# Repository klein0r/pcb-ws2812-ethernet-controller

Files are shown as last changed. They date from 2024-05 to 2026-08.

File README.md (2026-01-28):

# WS2812 / SK6812 Ethernet Controller Custom PCB

Control your addressable LED with custom software like [WLED](https://github.com/Aircoookie/WLED)

[Gerber-Files](https://github.com/klein0r/pcb-ws2812-ethernet-controller/releases)

## Important notes

The [WT32-ETH01](https://en.wireless-tag.com/product-item-2.html) has been released in different revisions. This adapter has been tested with revision 1.2 (length of the WT32-ETH01 PCB is ~5.5 cm).

**Some revisions may not fit!** I've received a photo of revision 1.4 with a PCB length of ~6.0 cm. Use PCB version 2.0 (or later) of this project to ensure the adapter will fit.

## Preview

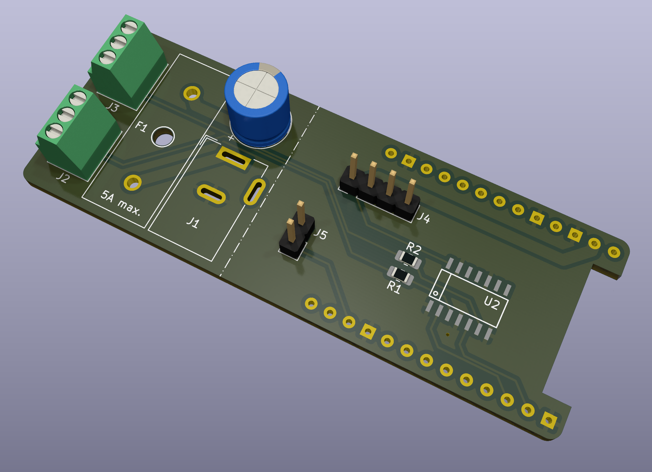
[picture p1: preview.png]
PCB Preview


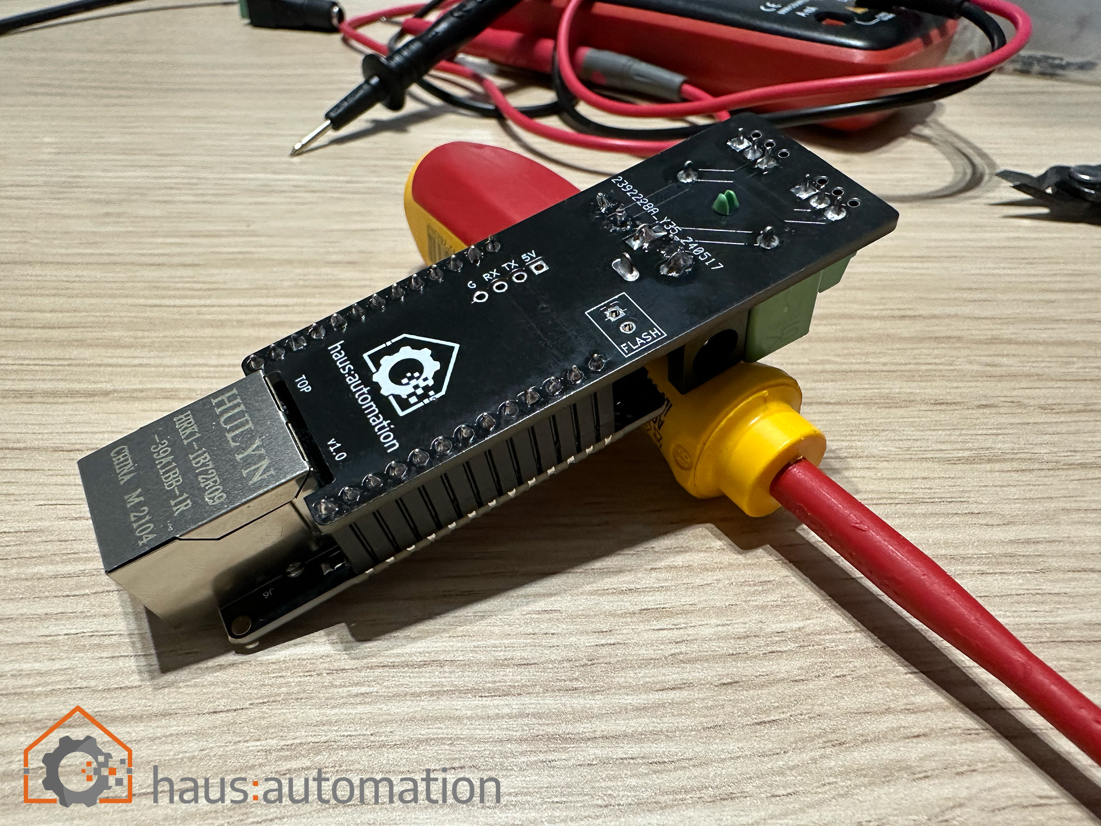
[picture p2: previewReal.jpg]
PCB Photo


## Components

- U1: WT32-ETH01 ESP32
- U2: SN74AHCT125DR
- C1: Capacitor Radial 3.8mm 1000μF 6.3V
- F1: Stelvio Kontek STV PTF/75 + Fuse 5x20mm, 5A (max. 6A)
- J1: Barrel Jack Connector - Wuerth 6941xx301002
- J2: PHC 1725669 - MPT 0,5 / 3-2,54
- J3: PHC 1725669 - MPT 0,5 / 3-2,54
- J4: 1x4 2.54mm Male Pin Headers (for flashing - soldering not required)
- J5: 1x2 2.54mm Male Pin Headers (for flashing - soldering not required / jumper)
- R1: Resistor 0805 330
- R2: Resistor 0805 330

[Component list (Affiliate-Link)](https://haus-auto.com/p/rei/ListeWS2812Eth)

## GPIO

- GPIO2 = Data line 1 of addressable strip
- GPIO4 = Data line 2 of addressable strip

## License

The MIT License (MIT)

Copyright (c) 2026 Matthias Kleine <info@haus-automatisierung.com>

Permission is hereby granted, free of charge, to any person obtaining a copy
of this software and associated documentation files (the "Software"), to deal
in the Software without restriction, including without limitation the rights
to use, copy, modify, merge, publish, distribute, sublicense, and/or sell
copies of the Software, and to permit persons to whom the Software is
furnished to do so, subject to the following conditions:

The above copyright notice and this permission notice shall be included in
all copies or substantial portions of the Software.

THE SOFTWARE IS PROVIDED "AS IS", WITHOUT WARRANTY OF ANY KIND, EXPRESS OR
IMPLIED, INCLUDING BUT NOT LIMITED TO THE WARRANTIES OF MERCHANTABILITY,
FITNESS FOR A PARTICULAR PURPOSE AND NONINFRINGEMENT. IN NO EVENT SHALL THE
AUTHORS OR COPYRIGHT HOLDERS BE LIABLE FOR ANY CLAIM, DAMAGES OR OTHER
LIABILITY, WHETHER IN AN ACTION OF CONTRACT, TORT OR OTHERWISE, ARISING FROM,
OUT OF OR IN CONNECTION WITH THE SOFTWARE OR THE USE OR OTHER DEALINGS IN
THE SOFTWARE.

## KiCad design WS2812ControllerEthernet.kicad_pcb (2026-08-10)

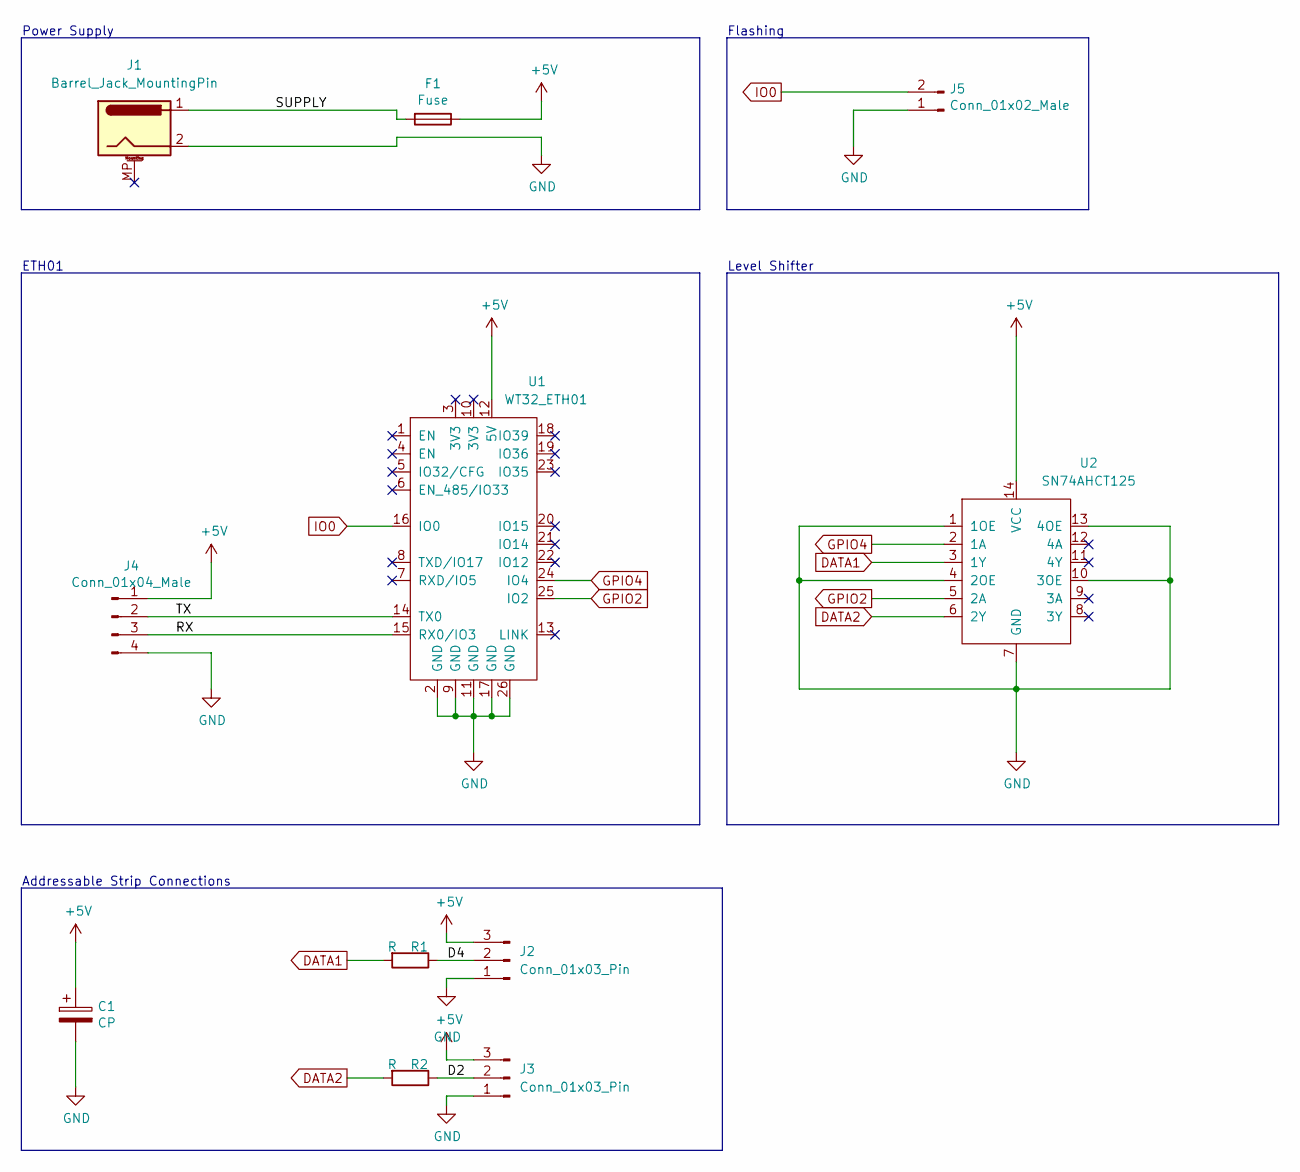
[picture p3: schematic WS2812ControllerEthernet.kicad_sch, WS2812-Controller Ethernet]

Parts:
C1: CP; CP_Radial_D8.0mm_P3.80mm
F1: Fuse; Fuse-PTF75_Stelvio
J1: Barrel_Jack_MountingPin; BarrelJack_Wuerth_6941xx301002
J2, J3: Conn_01x03_Pin; TerminalBlock_Phoenix_MPT-0,5-3-2.54_1x03_P2.54mm_Horizontal
J4: Conn_01x04_Male; PinHeader_1x04_P2.54mm_Vertical
J5: Conn_01x02_Male; PinHeader_1x02_P2.54mm_Vertical
R1, R2: R; R_0805_2012Metric_Pad1.20x1.40mm_HandSolder
U1: WT32_ETH01; WT32_ETH01_long
U2: SN74AHCT125; SN74AHCT125D

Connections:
+5V: C1.1, F1.1, J2.3, J3.3, J4.1, U1.12 (5V), U2.14 (VCC)
/D2: J3.2, R2.1
/D4: J2.2, R1.1
/RX: J4.3, U1.15 (RX0/IO3)
/SUPPLY: F1.2, J1.1
/TX: J4.2, U1.14 (TX0)
DATA1: R1.2, U2.3 (1Y)
DATA2: R2.2, U2.6 (2Y)
GND: C1.2, J1.2, J2.1, J3.1, J4.4, J5.1, U1.2 (GND), U1.9 (GND), U1.11 (GND), U1.17 (GND), U1.26 (GND), U2.1 (1OE), U2.4 (2OE), U2.7 (GND), U2.10 (3OE), U2.13 (4OE)
GPIO2: U1.25 (IO2), U2.5 (2A)
GPIO4: U1.24 (IO4), U2.2 (1A)
IO0: J5.2, U1.16 (IO0)

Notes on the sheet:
Addressable Strip Connections
Power Supply
ETH01
Flashing
Level Shifter

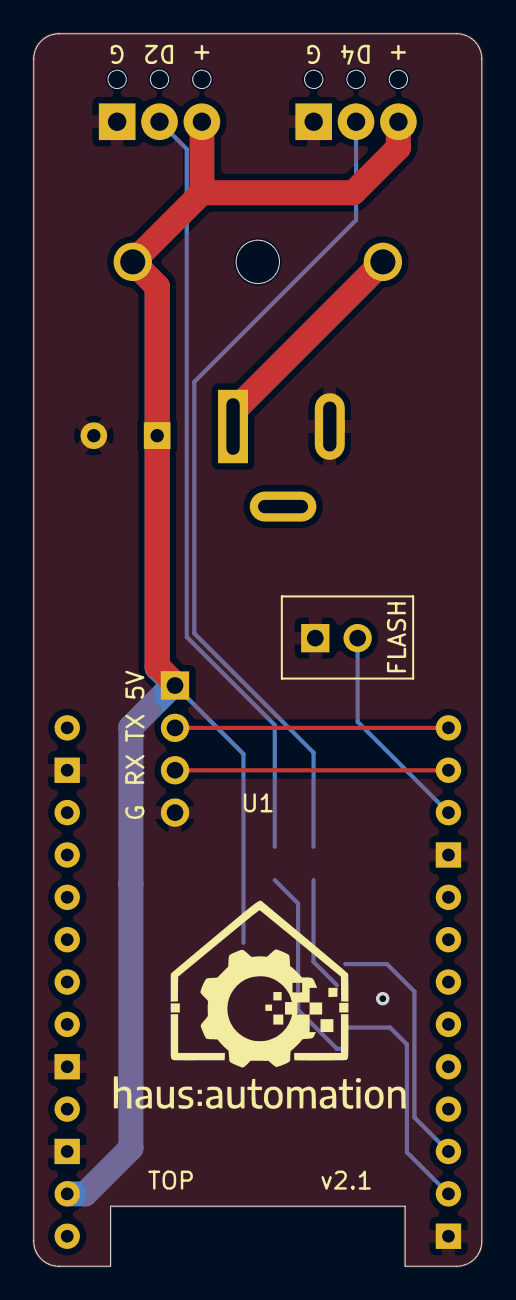
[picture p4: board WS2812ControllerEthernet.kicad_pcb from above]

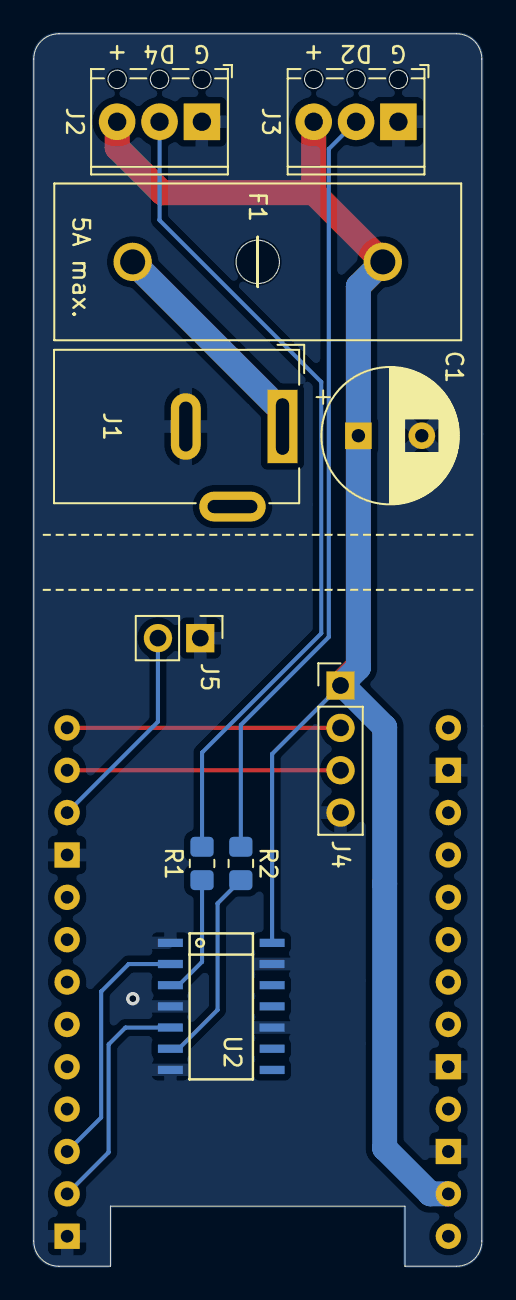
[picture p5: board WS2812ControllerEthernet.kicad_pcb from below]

Board: 2 copper layers, 26.9 x 73.9 mm, 11 parts (10 on the bottom side), 12 nets.

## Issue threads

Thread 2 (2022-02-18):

Levelshifter on preview but not in gerber-files

lebowski42, 2022-02-18:
Hi,
the preview shows pads for an level shifter (SN74AHCT125DR). Opening the KiCad-Files i also can see this component. But this component is missing in the previesReal.png and the prebuild gerber-files (gerber.zip).
Can you tell me, what is the right version (with SN74AHCT125DR or without)?

Thank you.

lebowski42, 2022-02-18:
Ok, thank you.
I'll give the new version a try and will post it here.

lebowski42, 2022-02-18:
And just another question: Why do you use an 330Ohm resistor for the data output and not 62 Ohm as suggested in the wled doc: https://kno.wled.ge/basics/getting-started/

klein0r, 2022-02-21:
You find hundreds of different recommendations for that resistor.

Adafruit: https://learn.adafruit.com/adafruit-neopixel-uberguide/best-practices

> Place a 300 to 500 Ohm resistor between the Arduino data output pin and the input to the first NeoPixel.

or https://forum.arduino.cc/t/new-to-sk6812-rgbw-led-strip-am-i-doing-this-right/562072

Feel free to use 62Ohm 😄

Closed 2022-02-21.

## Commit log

2021-05-12 Work in Progress
    [WS2812ControllerEthernet.kicad_pcb, WS2812ControllerEthernet.sch]
2021-05-13 First release, ready to order
    [WS2812ControllerEthernet.kicad_pcb, WS2812ControllerEthernet.sch]
2021-06-10 Fixed wrong label
    [WS2812ControllerEthernet.kicad_pcb, WS2812ControllerEthernet.sch]
2021-09-30 Added level shifter
    [WS2812ControllerEthernet.kicad_pcb, WS2812ControllerEthernet.sch]
2022-01-30 Updated to KiCad 6
    [WS2812ControllerEthernet.kicad_pcb, WS2812ControllerEthernet.kicad_sch, WS2812ControllerEthernet.sch]
2023-08-03 Updated layout
    [WS2812ControllerEthernet.kicad_pcb, WS2812ControllerEthernet.kicad_sch]
2024-02-19 Added additional GPIO for strip
    [WS2812ControllerEthernet.kicad_pcb, WS2812ControllerEthernet.kicad_sch]
2024-05-07 KiCad 8
    [WS2812ControllerEthernet.kicad_pcb, WS2812ControllerEthernet.kicad_sch]
2025-08-14 KiCad 9
    [WS2812ControllerEthernet.kicad_pcb, WS2812ControllerEthernet.kicad_sch]
2026-08-10 KiCad 10
    [WS2812ControllerEthernet.kicad_pcb, WS2812ControllerEthernet.kicad_sch]
